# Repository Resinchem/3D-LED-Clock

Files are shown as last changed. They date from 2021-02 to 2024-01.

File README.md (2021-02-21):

# 3D-LED-Clock

## 3D Printed LED clock, countdown timer, temperature and scoreboard. Multiple control options. Now with OTA updates!
ClockMontage_HA_Small

## Local button control
ClockButtonControl_small

## Optional full settings and control via Home Assistant integration (MQTT)
clock_ha_scoreboard_small

## Full build details, wiring schematics and more at [ResinChem Tech Blog](https://resinchemtech.blogspot.com/2021/02/3d-printed-clock-scoreboard-and-more.html)

### For more information on installation, configuration and other details, see the [wiki](https://github.com/Resinchem/3D-LED-Clock/wiki).

Modified based on an original design by Leon van den Beukel.

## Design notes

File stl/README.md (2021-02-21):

# 3D Models

### All models can be printed without supports, **EXCEPT** the ControlEnclosure.stl, which should have supports enabled.

### To build the clock as designed, you will need to print each file by the listed quantity below:

| Qty | .stl File | Descrip | Color |
|:---:|---|---|---|
| 4 | Bottom.stl | Bottom Plates | Black |
| 4 | Top.stl | Top Plates | Black |
| 1 | Middle.stl | Middle top/bottom | Black |
| 1 | AttachBrackets_x6.stl | Rear attach brackets | Black |
| 1 | Backlid.stl | Back lid cover | Black |
| 1 | Stand_Spacers.stl | Clock Stand | Black |
| 1 | ButtonCase.stl | Push Button Enclosure | Black |
| 1 | ControlEnclosure.stl | Control board box | Black |
| 2 | Segment_hor_x6.stl | Six horiz. digit segments | White |
| 2 | Segment_vert_x8.stl | Eight vert. digit segments | White |
| 1 | Dot_x2.stl | Two dots | White |

Here are the settings I used for the Ender3 Pro:
- Layer Height: 0.2
- Infill: 20%
- Supports: No*
(\*Except for the Control Enclosure, which used supports touching buildplate)

#### See [ResinChem Tech Blog](https://resinchemtech.blogspot.com/2021/02/3d-printed-clock-scoreboard-and-more.html) for complete build details, parts list, wiring schematics and more.

All .stl files original design, except for ButtonCase.stl and ControlEnclosure, by Leon van den Beukel.

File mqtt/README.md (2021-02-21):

# MQTT Topic Commands and States

### MQTT use is optional, but if desired, a few steps must be taken

See the [MQTT page](https://github.com/Resinchem/3D-LED-Clock/wiki/MQTT-%5C---Home-Assistant-Integration) of the wiki for additional information.

The full list of topic states and commands, and valid payloads, can be found in the MQTT_Topics.pdf file.  Currently, there are over 30 states reported by the clock and over 20 commands that can be issued to the clock over MQTT.

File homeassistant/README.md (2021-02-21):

# Sample Home Assistant Files

### These are sample .yaml files that you can use or adapt to integrate the clock into Home Assistant

All communications between the clock (ESP8266) and Home Assistant are via MQTT.  Currently, the clock does not support MQTT discovery (anyone willing to take a stab at this is welcome to submit a PR), therefore all entites must be manually created in Home Assistant.  Obviously, you must have an MQTT broker running (either the integrated HA Mosquitto or a standalone broker).

MQTT is not required to build and use the clock. MQTT can be disabled within the Arudino sketch by setting MQTTMODE = 0 in the Settings.h file. See the [wiki](https://github.com/Resinchem/3D-LED-Clock/wiki) for additional details.

The samples include every possible sensor value and commands available for the clock.  You may not wish to include them all.

The entities also have long descriptive names in an attempt to clarify how they are used.

You can safely edit most of the yaml to fit your needs.  However, you cannot changes any of the MQTT topics or payloads without also modifying and uploading a new Arduino .ino file to the ESP8266 board.

For the Lovelace card, two custom cards (available via HACS) are necessary:

[Custom Button Card](https://github.com/custom-cards/button-card)

[Text-Divider-Row](https://github.com/iantrich/text-divider-row)

The files here are just starting examples.  Many, many more automations are possible and if you'd like to share any you develop, I'll post the interesting ones here.  But some examples might include:
- Change the clock color and/or brightness based on sun (or any other event)
- Sound the buzzer based on any other HA event or state change.
- Use the countdown feature to trigger other automations.

With over 30 MQTT sensors and over 20 MQTT commands, the possibilites are endless. See a full list of MQTT topcis in the MQTT folder.

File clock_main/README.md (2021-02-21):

# Arduino Files

There are some additional steps you must complete before uploading the .ino file to your board.  See the [Installation page](https://github.com/Resinchem/3D-LED-Clock/wiki/Installation) of the wiki for full installation instructions.

### Additional Information:
Full details on the build, including parts list, wiring schematics and more can be found at [ResinChem Tech Blog](https://resinchemtech.blogspot.com/2021/02/3d-printed-clock-scoreboard-and-more.html)

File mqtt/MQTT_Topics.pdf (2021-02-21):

## LED Clock MQTT Reporting States (clock publishes to these topics)

Topic Root | Topic | Subtopic1 | Subtopic2 | Payload | Values / Notes
stat/ledclock | /mode | | | mode (string) | Clock, Countdown, Temperature, Scoreboard
| /brightness | | | 0-255
| /clock | /display | | nn | 12 or 24
| | /color | /red | 0-255
| | /color | /green | 0-255
| | /color | /blue | 0-255
| /countdown | /starttime | | hh:mm:ss | Example: "00:15:00"
| | /status | | status as string | Running or Stopped
| | /color | /red | 0-255
| | /color | /green | 0-255
| | /color | /blue | 0-255
| | /colorfinalmin | /red | 0-255
| | /colorfinalmin | /green | 0-255
| | /colorfinalmin | /blue | 0-255
| | /colorpaused | /red | 0-255
| | /colorpaused | /green | 0-255
| | /colorpaused | /blue | 0-255
| /temperature | | | nn.n | Updates every 3 min or as specified in sketch
| | /symbol | | string char | C or F
| | /correction | | (-)n.n | Example: -6.5
| | /color | /red | 0-255
| | /color | /green | 0-255
| | /color | /blue | 0-255
| /scoreboard | /scoreleft | | 0-99
| | /scoreright | | 0-99
| | /colorleft | /red | 0-255
| | /colorleft | /green | 0-255
| | /colorleft | /blue | 0-255
| | /colorright | /red | 0-255
| | /colorright | /green | 0-255
| | /colorright | /blue | 0-255
Rebooting/restarting the clock will reset values to the defaults defined in the Settings.h file.

## All state topics begin with a topic of: stat/ledclock Examples: Get the current mode of the clock: MQTT Topic: stat/ledclock/mode Payload Returns: String of the clock mode (Clock, Countdown, Temperature or Scoreboard)

## Get the current RGB blue value setting of the scoreboard left score: MQTT Topic: stat/ledclock/scoreboard/colorleft/blue

Payload Returns: A value between 0-255 of the current RGB blue value for the left score.

## LED Clock Commands (clock subscribes to these topics)

Topic Root | Topic | Subtopic | Payload | Changes
Mode

Notes
cmnd/ledclock/ | /mode | n | Yes | Valid values: 0 (clock), 1 (countdown), 2
(temperature), 3 (scoreboard)
/brightness | nnn | Valid values: 0-255
/buzzer | nnnn | 1-9999 (milliseconds to sound)
/clock | /color | nnn,nnn,nnn | RGB: 0-255 range for each color
/display | nn | Yes | Valid values: 12 or 24
/settime | mmm dd yyyy;hh:mm:ss | Yes | mmm = Jan, Feb, Mar, etc.
/countdown | /color | nnn,nnn,nnn | RGB: 0-255 range for each color
/colorfinalmin | nnn,nnn,nnn | RGB: 0-255 range for each color
/colorpaused | nnn,nnn,nnn | RGB: 0-255 range for each color
/starttime | hh:mm:ss | Yes | Max of 23:59:59 (split and convert to
milliseconds)
/action | n | Yes | Valid values: 0 (Start), 1 (pause), 2 (stop &
reset), 3 (stop & clear)
/temperature | /color | nnn,nnn,nnn | RGB: 0-255 range for each color
/symbol | nn | Yes | Valid values: 12 (Celsius), 13 (Fahrenheit)
/correction | -n or +n | Yes | Examples: -4 or 2.5
/scoreboard | /colorleft | nnn,nnn,nnn | RGB: 0-255 range for each color
/colorright | nnn,nnn,nnn | RGB: 0-255 range for each color
/scoreleft | nn | Yes | Valid values: 0-99
/scoreright | nn | Yes | Valid values: 0-99
/scoreup | n | Yes | Increases by one. n=0 Left, n=1 Right, n=2 Both
/scoredown | n | Yes | Decreases by one. n=0 Left, n=1 Right, n=2 Both
/reset | n | Yes | Reset to zero: n=0 left, n=1 right, n=2 both

Changes Mode: Issuing the command also changes the current clock mode (e.g. changing the score also changes the clock mode to Scoreboard).

## Examples: Change the color of the clock to red: Topic: cmnd/ledclock/clock/color Payload: 255,0,0

## Set the starting time for the countdown to 2 minutes, 30 seconds: Topic: cmnd/ledclock/countdown/starttime Payload: 00:02:30

## Reset the scoreboard scores for both sides to zero: Topic: cmnd/ledclock/scoreboard/reset Payload: 2

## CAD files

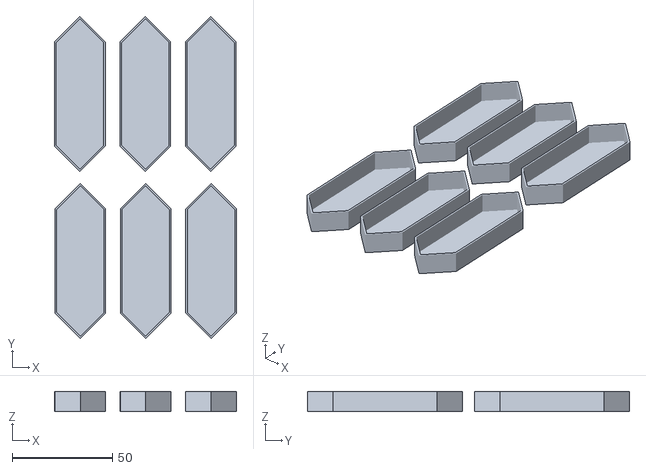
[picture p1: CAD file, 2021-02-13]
stl/Segment_hor_x6.stl
91.0 x 161.0 x 10.0

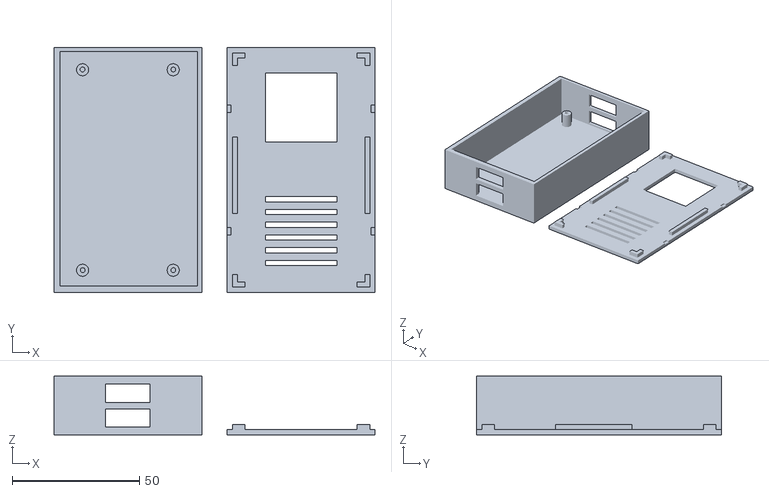
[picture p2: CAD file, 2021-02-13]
stl/ControlEnclosure.stl
126.0 x 96.0 x 23.0

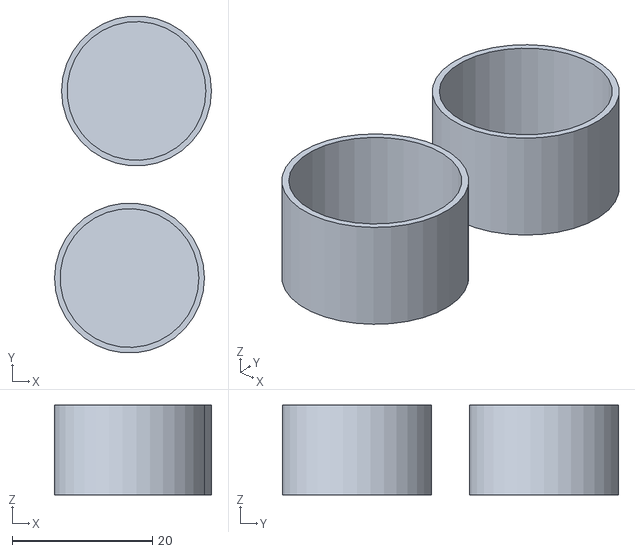
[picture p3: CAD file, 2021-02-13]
stl/Dot_x2.stl
22.4 x 48.0 x 12.8

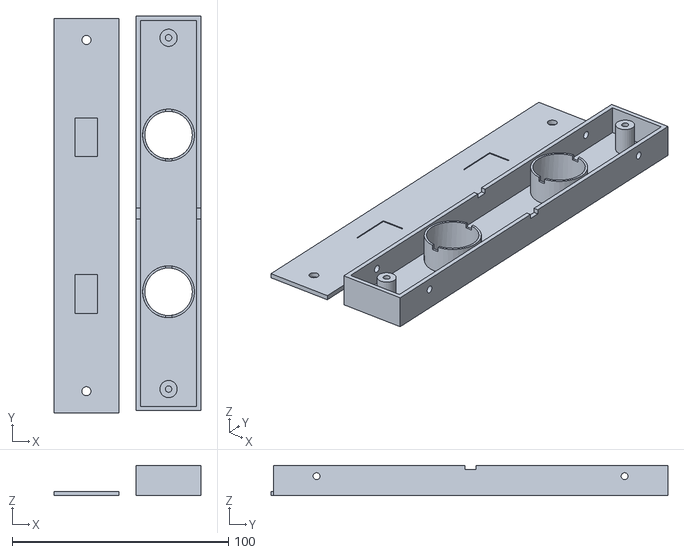
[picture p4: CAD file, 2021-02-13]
stl/Middle.stl
68.0 x 183.5 x 14.0

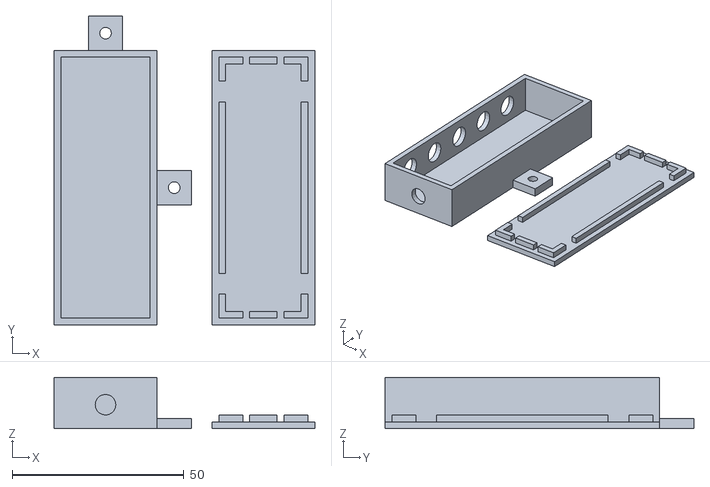
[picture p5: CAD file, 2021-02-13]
stl/ButtonCase.stl
76.0 x 90.0 x 15.0

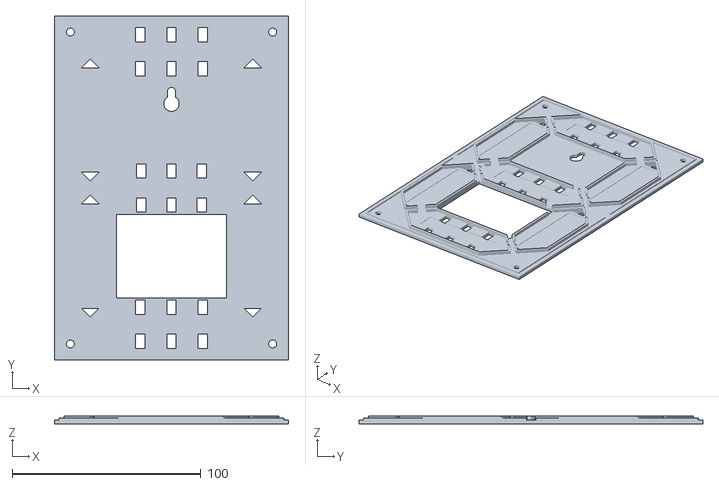
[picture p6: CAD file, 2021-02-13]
stl/Bottom.stl
124.2 x 182.5 x 4.00

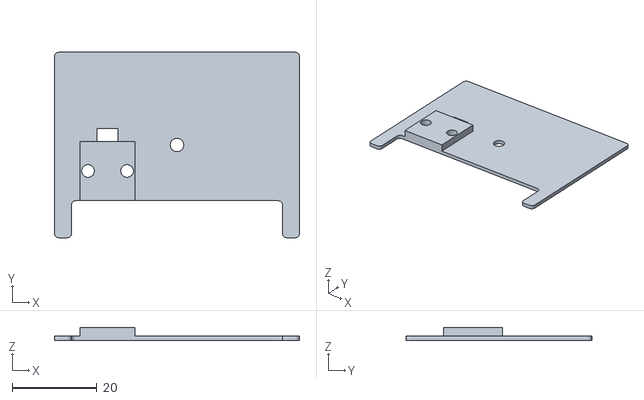
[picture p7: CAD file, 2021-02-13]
stl/Backlid.stl
57.7 x 43.7 x 3.00

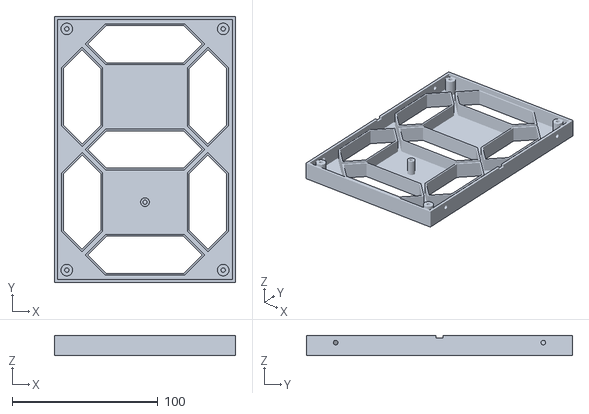
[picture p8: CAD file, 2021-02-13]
stl/Top.stl
124.2 x 182.5 x 14.0

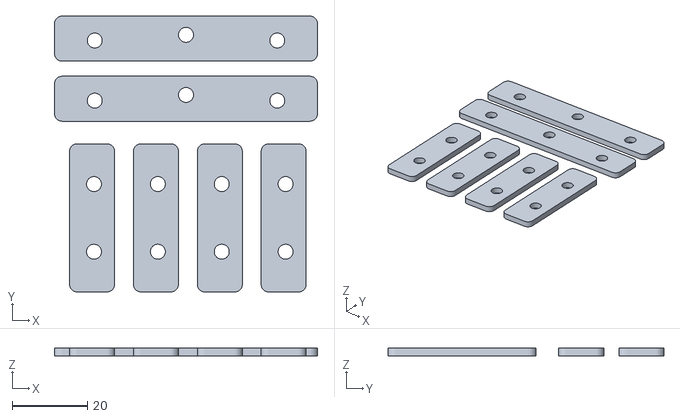
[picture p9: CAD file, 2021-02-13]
stl/AttachBrackets_x6.stl
70.0 x 73.4 x 2.00

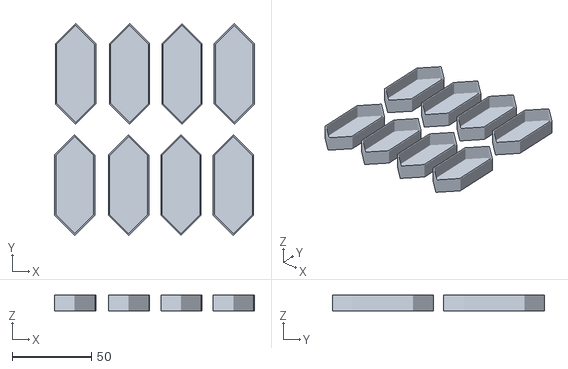
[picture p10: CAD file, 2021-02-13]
stl/Segment_vert_x8.stl
126.0 x 133.5 x 10.0

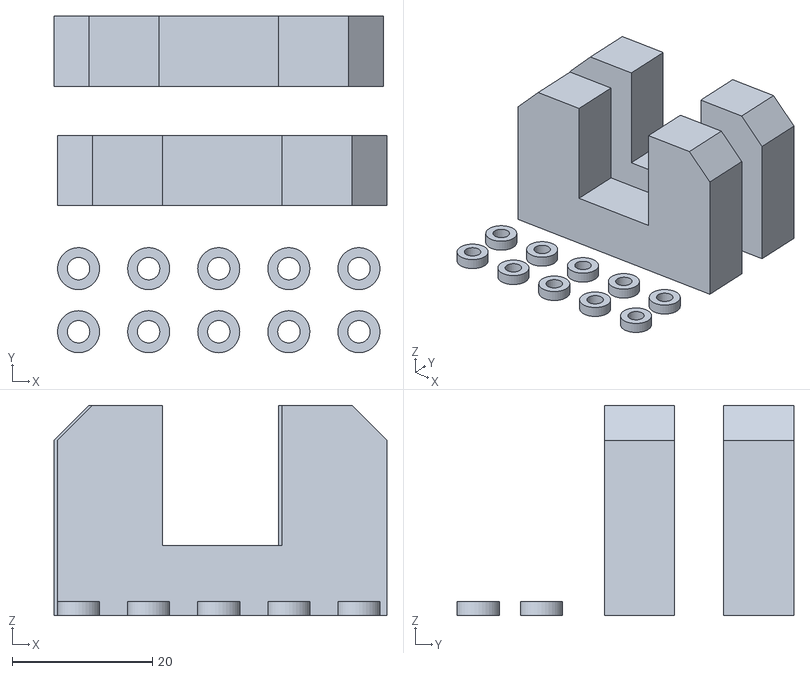
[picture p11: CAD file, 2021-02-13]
stl/Stand_Spacers.stl
47.5 x 48.0 x 30.0

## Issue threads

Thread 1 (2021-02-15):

Temperature not updating in Home Assistant when C/F or correction value entered

Resinchem, 2021-02-15:
When temperature display (C to F, or F to C) is changed via web app or Home Assistant, the displayed temperature in Home Assistant is not updated.  For example if 72.5 is displayed in Home Assistant and the mode is switched to C. the clock properly changes, but the value in the Home Assistant integration continues to display 72.5.

The same issue is seen when updating the temperature correction value.

Resinchem, 2021-02-15:
Fixed in release v0.93.

Requires new clock_main.ino.  Be sure to transfer your settings and options (MQTT IP, PORT, defaults, etc.) to the new clock_main.ino before flashing to your board.

Closed 2021-02-15.

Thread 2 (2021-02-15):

Clock changing mode when Home Assistant server restarts/reboots.

Resinchem, 2021-02-15:
When Home Assistant starts or reboots, the clock changes mode to Temperature, regardless of the mode it was set to prior to the HA reboot.

Resinchem, 2021-02-15:
Fixed in release v0.93. This was caused by the 'initial: ' value setting of the input_text entities for temperature correction.  You can either download the updated input_text.yaml and integrate into your current one, or simply remove the 'initial:' property for the following input_text entities:

input_text.led_clock_temperature_correction
input_text.led_clock_countdown_starttime

Closed 2021-02-15.

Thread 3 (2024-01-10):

Compilation error after disable MQTT in settings.h

JureqB, 2024-01-10:
...  Documents\Arduino\3D-LED-Clock-1.00\clock_main\clock_main.ino: In function 'boolean reconnect()':
clock_main:95:37: error: 'mqttUser' was not declared in this scope
   95 |   if (client.connect("ClockClient", mqttUser, mqttPW)) {
      |                                     ^~~~~~~~
clock_main:95:47: error: 'mqttPW' was not declared in this scope
   95 |   if (client.connect("ClockClient", mqttUser, mqttPW)) {
      |                                               ^~~~~~
exit status 1
'mqttUser' was not declared in this scope

Resinchem, 2024-01-10:
There were some missing checks for the MQTT enabled status.  These have been fixed with release v1.01.

Closed 2024-01-10.

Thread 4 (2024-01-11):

#define MQTTMODE 0 in settings.h still generating error

JureqB, 2024-01-11:
...  Documents\Arduino\3D-LED-Clock-1.01\clock_main\clock_main.ino: In function 'boolean reconnect()':
clock_main:106:1: error: no return statement in function returning non-void [-Werror=return-type]
  106 | }

Resinchem, 2024-01-11:
I'm not able to duplicate this issue as the code compiles fine for me whether the MQTT mode in settings is set to either 1 or 0.  However, you can try adding an #else statement in the reconnect function to see if it solves your issue:

```
boolean reconnect() {
#if (WIFIMODE == 1 || WIFIMODE == 2) && (MQTTMODE == 1)
  if (client.connect("ClockClient", mqttUser, mqttPW)) {
    // Once connected, publish an announcement...
    client.publish("stat/ledclock/status", "connected");
    // ... and resubscribe
    client.subscribe("cmnd/ledclock/#");
  }
  return client.connected();
#else
  return true;
#endif
}
```
You can try adding the #else and return true lines to your version and see if it resolves the issue.  But it shouldn't be required as I am not getting any compilation errors without it.  As an FYI, I am using the Arduino IDE v1.8.16.

JureqB, 2024-01-11:
I am using 1.18.19 (Windows Store 1.8.57.0)

When I have MQTT enabled, I can compile oryginal a sketch and only this message appears:

In file included from C:\Users\xyz\Documents\Arduino\libraries\FastLED\src/FastLED.h:79,
                 from C:\Users\xyz\Documents\Arduino\3D-LED-Clock-main\clock_main\clock_main.ino:13:
C:\Users\xyz\Documents\Arduino\libraries\FastLED\src/fastspi.h:157:23: note: '#pragma message: No hardware SPI pins defined.  All SPI access will default to bitbanged output'
  157 | #      pragma message "No hardware SPI pins defined.  All SPI access will default to bitbanged output"
      |                       ^~~~~~~~~~~~~~~~~~~~~~~~~~~~~~~~~~~~~~~~~~~~~~~~~~~~~~~~~~~~~~~~~~~~~~~~~~~~~~~~

JureqB, 2024-01-11:
Serial monitor at 74880 baud received this:

15:55:26.108 ->  ets Jan  8 2013,rst cause:2, boot mode:(3,6)
15:55:26.108 ->
15:55:26.108 -> load 0x4010f000, len 3424, room 16
15:55:26.155 -> tail 0
15:55:26.155 -> chksum 0x2e
15:55:26.155 -> load 0x3fff20b8, len 40, room 8
15:55:26.155 -> tail 0
15:55:26.155 -> chksum 0x2b
15:55:26.155 -> csum 0x2b
15:55:26.155 -> v000618e0
15:55:26.155 -> ~ld
15:55:26.202 -> rf cal sector: 1020
15:55:26.202 -> freq trace enable 0
15:55:26.202 -> rf[112] : 0⸮

Resinchem, 2024-01-11:
From the serial monitor, the rst cause:2, boot mode(3,6) is usually due to a watchdog reset.  This means something is hanging in your program.  It could be the real time clock, connection to wifi taking longer than expected, or some other peripheral that isn't wired correctly and is not reporting back as expected.  I'd recommend verifying all your wiring, and if necessary, add some Serial.println() statements to various sections of the setup code to see where the application is hanging up.

Also the fact that you are seeing the clock AP being broadcast means that it isn't connecting to your wifi.  Verify your WiFi settings in Credentials.h.  You can also try setting WIFIMODE to 1 in the Settings.h, meaning that it will only connect to your wifi and not broadcast a local AP hotspot.

Unfortunately, I cannot duplicate the issue.  Mine compiles and runs just fine, with or without MQTT.  The 3D printed clock has been in operation for nearly 3 years now and I haven't seen or noticed any watchdog resets like you are reporting, so I don't believe this is a firmware issue but something likely due to your particular build.

Resinchem, 2024-01-11:
OK... our messages crossed paths.  First, the SPI message you are seeing is normal and isn't an error.  Next, the watchdog resets are likely a result of the missing RTC clock module.  The clock calls this module to get the current time... and I'm guessing that since you don't have the clock module connected, this is what is causing the reboots.

If the clock is constantly rebooting due to this watchdog error, it probably also explains why you cannot bring up the web page... the ESP is constantly rebooting and is unable to start the web server and respond to the web request.

For this particular code and the way it is written, the RTC module is required.

JureqB, 2024-01-11:
I don't currently have the RTC module, once I put it all together I will let you know if there is any improvement, thank you for your help :)

Resinchem, 2024-01-11:
No problem.  Glad to help.  This is one of my earliest Arduino projects and there is a ton of room for improvement.  It's one of many projects I'd like to revisit and clean up the code... if I can ever find time to do it.

I'm going to go ahead and close this issue for now.  If you have problems or errors after connecting the RTC module, feel free to open a new issue.

Resinchem, 2024-02-02:
First off, you should not be trying to power everything via USB.  The LEDs can pull over 4A depending upon color/brightness.  It is recommended that no more than about 500 mA be pulled on he 5V pin on the D1 Mini/ESP8266.  Trying to run everything via USB will likely damage or destroy the ESP board at some point.  I think my build recommended a 5V 8A power supply and the board, as built, supplies power to the LEDs and controller in parallel so that the total current isn't running through the ESP board.

That being said, the error you are getting is a watchdog reset.  This is generally due to something hanging or taking too long to complete, which results in a reboot of the board.  The fact that the 'points' are delayed at times and that they work fine when in other modes (such as timer), points to something hanging up or delaying in the updateClock process.  And the one thing that is different about that process is the real time clock module (RTC).  It is highly likely that it is this module that is causing a delay when it is called (Rtc.GetDateTime).  This would explain both the delay in the dots updating and the reboot if the delay is too long.

So you probably need to focus on the RTC module... assure it is properly wired, has a fresh battery, etc.  It could also be causing issues if underpowered (e.g when powering via USB or an underpowered power supply). You should also verify that it is one of the supported chip sets for the RTC library being used.  You can get that info here:  [RTC Library Wiki](https://github.com/Makuna/Rtc/wiki).

But the fact that other modes work fine and only the clock is having these issues points to either a problem with the RTC module and/or the system being underpowered.  I'd recommend using a power supply that can supply at least 5A, preferably 8-10A.

JureqB, 2024-02-06:
I have used various 3-10A power supplies and it does not matter. Current consumption during operation does not exceed 1.5A. Only when I turned off Wi-Fi+AP mode and left Wi-Fi anly (#define WIFIMODE 1) did the dots blink as they should. So it's a program problem, not an external one.

Resinchem, 2024-02-06:
Do you have MQTT configured and enabled (MQTTMODE = 1)?  There are really only two things in the main loop that could cause a significant delay (which would impact the blinking dots) or even a watchdog reset... waiting on the RTC module to return a valid value, or trying to connect/reconnect to the MQTT broker.  The Wifi or Wifi+AP mode really shouldn't make a difference.  The only difference between these two settings is whether the ESP continues to broadcast its hotspot after connecting to wifi (mode 2) or turns it off (mode 1).

It is entirely possible that I missed something, especially if MQTT is not configured or off... or I missed a combination check of both Wifi and MQTT modes to determine whether to use MQTT or not.  But I have successfully been running this code for multiple years on this 3D clock.  I also have 3 matrix clocks, and while the output to LEDs are different, the rest of the application logic is basically the same.  But I do have MQTT enabled for all of these.
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
JureqB, 2024-02-06:
I don't have MQTT (MQTTMODE 0   MQTTSERVER "0.0.0.0"  MQTTPORT 1883) , but my first problem, as you remember, was that I couldn't compile the program after turning off MQTT in settings.h

Resinchem, 2024-02-06:
OK... thanks.  Even though I fixed the compile errors, I most likely I missed something somewhere where it is still trying to connect to your non-existent MQTT broker.  Since I'm using MQTT, I didn't actually install and test the last fix... just the fact that it compiled.

Give me a little time and as soon as I get a chance, I'll circle back to the code and go over it again and assure that it is not making any calls to MQTT if the option is disabled.

Resinchem, 2024-02-06:
OK... I've reviewed the code and I don't see anything related to MQTT.  If you set MQTTMODE = 0, most of MQTT functions and processes don't even get compiled into the firmware.  But I was looking back through what we discussed above and something caught my eye.  You said that the dots function normally for things like the timer, but are only acting unusual and delaying when in clock mode.  In the main loop, every 1 second it calls the method to update the display (either via updateClock, updateCountdown, updateScoreboard, etc.).

Well, in the updateClock function is this call that isn't present in any of the other update methods:

```  RtcDateTime now = Rtc.GetDateTime();```

So this points back to a potential issue with the clock module and/or its communication with the D1 Mini.  The clock would appear to keep the correct time, as it only updates once per minute... and that timer is kept within the main loop.  But the dot update (toggling the dots on/off) is occurring within the individual updates (clock, timer, etc.).  So, if the clock update is taking too long to communicate with the RTC module, the dots will be delayed in turning off/on, but the master loop keeps counting, so the minute will roll forward at the 60 second mark (unless it is delayed in the loop right at that moment).  That would also explain why the dots work normally in the timer mode, as it isn't calling the RTC module.  Here's a test you can try that might confirm the problem:

Start a stopwatch right when a new minute is displayed.  Watch it for 5 or 10 minutes.  The clock should update to the next minute right at 60 seconds.  If you are seeing a one or two second difference (or even greater), then the updateClock procedure is causing a delay.  But since the 60 second counter continues to run in the main loop, you may not see this right away.  So if you don't see a difference in the first 5-10 minutes, let both the stopwatch and clock run and come back every so often (maybe every hour or two) and see if the clock is still in sync with the stopwatch... updating the time at the top of minute on the stopwatch.  If the update has drifted over time, this also indicates that the clockUpdate is taking too long and causing a drift over time.  Unless you are pressing a bunch of the pushbuttons (these actually consume a couple hundred milliseconds), then the clock time should not drift by more than a couple of seconds MAX over a 24-hour period.

I don't think MQTT is the issue any longer.  But it does appear to be something limited to the clock mode and the only real difference between that mode and the other modes is the call made to the RTC library/module.  Please let me know what you find based on the above and we can take it from there.

Closed 2024-01-11.

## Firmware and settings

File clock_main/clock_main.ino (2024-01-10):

/*
 * VERSION 1.01
 * January 10, 2024
 * See Release notes for details on changes
 * By ResinChem Tech - licensed under Creative Commons Attribution-NonCommercial-ShareAlike 4.0 International License
 * Adapted from original work published by Leon van den Beukel 
*/
#include <Wire.h>
#include <RtcDS3231.h>                        // Include RTC library by Makuna: https://github.com/Makuna/Rtc
#include <ESP8266WiFi.h>
#include <ESP8266WebServer.h>
#include <ESP8266HTTPUpdateServer.h>
#include <FastLED.h>
#include <FS.h>                               // Please read the instructions on http://arduino.esp8266.com/Arduino/versions/2.3.0/doc/filesystem.html#uploading-files-to-file-system
#include <PubSubClient.h>
#include <ESP8266mDNS.h>                      // NEW for v1.00
#include <WiFiUdp.h>                          // NEW for v1.00
#include <ArduinoOTA.h>                       // NEW for v1.00
#include "Settings.h"
#define countof(a) (sizeof(a) / sizeof(a[0]))

// ==============================================================================================
//  *** REVIEW THE Settings.h and Credentials.h FILES AND SET TO MATCH YOUR ENVIRONMENT/BUILD ***
//      You may also set various default boot options in the Settings.h file
// ==============================================================================================
// Do not change any values below unless you are sure you know what you are doing!

byte oldMode = 0;
int oldTemp = 0;
bool ota_flag = true;               //v1.00
uint16_t ota_time_elapsed = 0;      //v1.00
uint16_t ota_time_window = 2500;    //v1.00 minimum time on boot for IP address to show in IDE ports


#if defined(WIFIMODE) && (WIFIMODE == 0 || WIFIMODE == 2)
  const char* APssid = "CLOCK_AP";        
  const char* APpassword = "1234567890";  
#endif
  
#if defined(WIFIMODE) && (WIFIMODE == 1 || WIFIMODE == 2)
  #include "Credentials.h"                    // Edit this file in the same directory as the .ino file and add your own credentials
  const char *ssid = SID;
  const char *password = PW;
  #if (WIFIMODE == 1 || WIFIMODE == 2) && (MQTTMODE == 1)    // MQTT only available when on local wifi
    const char *mqttUser = MQTTUSERNAME;
    const char *mqttPW = MQTTPWD;
  #endif
#endif
WiFiClient espClient;
#if (WIFIMODE == 1 || WIFIMODE == 2) && (MQTTMODE == 1)
  PubSubClient client(espClient);   
#endif
long lastReconnectAttempt = 0;

RtcDS3231<TwoWire> Rtc(Wire);
ESP8266WebServer server(80);
ESP8266HTTPUpdateServer httpUpdateServer;
CRGB LEDs[NUM_LEDS];

unsigned long prevTime = 0;
unsigned long prevTempTime = 0;                   // To limit MQTT Temp updates so as not to flood broker
byte r_val = 255;
byte g_val = 0;
byte b_val = 0;
bool dotsOn = true;
unsigned long countdownMilliSeconds;
unsigned long endCountDownMillis;

//
bool mqttConnected = false;                       // Will be set to true upon valid connection
bool timerRunning = false; 
unsigned long remCountdownMillis = 0;             // Stores value on pause/resume
unsigned long initCountdownMillis = 0;            // Stores initial last countdown value for reset    
//
long numbers[] = {
  0b000111111111111111111,  // [0] 0
  0b000111000000000000111,  // [1] 1
  0b111111111000111111000,  // [2] 2
  0b111111111000000111111,  // [3] 3
  0b111111000111000000111,  // [4] 4
  0b111000111111000111111,  // [5] 5
  0b111000111111111111111,  // [6] 6
  0b000111111000000000111,  // [7] 7
  0b111111111111111111111,  // [8] 8
  0b111111111111000111111,  // [9] 9
  0b000000000000000000000,  // [10] off
  0b111111111111000000000,  // [11] degrees symbol
  0b000000111111111111000,  // [12] C(elsius)
  0b111000111111111000000,  // [13] F(ahrenheit)
  0b000111000111111111111,  // [14] U
  0b111111111111111000000,  // [15] P
  0b000000000111111111000,  // [16] L
  0b111111000000111111111,  // {17] d
};

boolean reconnect() {
#if (WIFIMODE == 1 || WIFIMODE == 2) && (MQTTMODE == 1)
  if (client.connect("ClockClient", mqttUser, mqttPW)) {
    // Once connected, publish an announcement...
    client.publish("stat/ledclock/status", "connected");
    // ... and resubscribe
    client.subscribe("cmnd/ledclock/#");
  }
  return client.connected();
#endif
}

void setup() {
  pinMode(3, FUNCTION_3);
  pinMode(1, FUNCTION_3);
  pinMode(COUNTDOWN_OUTPUT, OUTPUT);
  pinMode(MODE_PIN, INPUT_PULLUP);
  pinMode(V1_PIN, INPUT_PULLUP);
  pinMode(V0_PIN, INPUT_PULLUP);
  pinMode(H1_PIN, INPUT_PULLUP);
  pinMode(H0_PIN, INPUT_PULLUP);
  delay(200);

  // RTC DS3231 Setup
  Rtc.Begin();    
  RtcDateTime compiled = RtcDateTime(__DATE__, __TIME__);

  if (!Rtc.IsDateTimeValid()) {
      if (Rtc.LastError() != 0) {
          // we have a communications error see https://www.arduino.cc/en/Reference/WireEndTransmission for what the number means
          // Serial.print("RTC communications error = ");
          // Serial.println(Rtc.LastError());
      } else {
          // Common Causes:
          //    1) first time you ran and the device wasn't running yet
          //    2) the battery on the device is low or even missing
          // Serial.println("RTC lost confidence in the DateTime!");
          // following line sets the RTC to the date & time this sketch was compiled
          // it will also reset the valid flag internally unless the Rtc device is
          // having an issue
          Rtc.SetDateTime(compiled);
      }
  }

  WiFi.setSleepMode(WIFI_NONE_SLEEP);  

  delay(200);

  FastLED.addLeds<WS2812B, DATA_PIN, GRB>(LEDs, NUM_LEDS);  
  FastLED.setDither(false);
  FastLED.setCorrection(TypicalLEDStrip);
  FastLED.setMaxPowerInVoltsAndMilliamps(5, MILLI_AMPS);
  fill_solid(LEDs, NUM_LEDS, CRGB::Black);
  FastLED.show();

  // WiFi - AP Mode or both
#if defined(WIFIMODE) && (WIFIMODE == 0 || WIFIMODE == 2) 
  WiFi.mode(WIFI_AP_STA);
  WiFi.softAP(APssid, APpassword);    // IP is usually 192.168.4.1
#endif

  // WiFi - Local network Mode or both
#if defined(WIFIMODE) && (WIFIMODE == 1 || WIFIMODE == 2) 
  byte count = 0;
  WiFi.begin(ssid, password);
  while (WiFi.status() != WL_CONNECTED) {
    // Stop if cannot connect
    if (count >= 60) {
      // Could not connect to local WiFi      
      return;
    }
    delay(500);
    LEDs[count] = CRGB::Green;
    FastLED.show();
    count++;
  }
  IPAddress ip = WiFi.localIP();
#endif   
  // MQTT - Only if on local wifi and MQTT enabled
#if defined(MQTTMODE) && (MQTTMODE == 1 && (WIFIMODE == 1 || WIFIMODE == 2))
  byte mcount = 0;
  client.setServer(MQTTSERVER, MQTTPORT);
  client.setCallback(callback);
  while (!client.connected( )) {
    client.connect("ClockClient", mqttUser, mqttPW);
    if (mcount >= 60) {
      // Could not connect to MQTT broker
      return;
    }
    delay(500);
    LEDs[mcount] = CRGB::Blue;
    FastLED.show();
    mcount++;
  }
  mqttConnected = true;
  client.subscribe("cmnd/ledclock/#");
  client.publish("stat/ledclock/status", "connected");
  oldMode = clockMode;
  updateMqttMode();
#endif
  httpUpdateServer.setup(&server);
  
  //OTA Updates - new in V1.00
  ArduinoOTA.setHostname("led-clock");
  ArduinoOTA.onStart([]() {
    String type;
    if (ArduinoOTA.getCommand() == U_FLASH) {
      type = "sketch";
    } else { // U_FS
      type = "filesystem";
    }
    // NOTE: if updating FS this would be the place to unmount FS using FS.end()
  });
  ArduinoOTA.begin();
  
  // ************ Update MQTT stat vals with boot values *****************
  if (mqttConnected) {
    updateMqttBrightness(brightness);
    updateMqttClockDisplay(hourFormat);
    updateMqttTemperature();
    updateMqttTempSymbol(temperatureSymbol);
    updateMqttTempCorrection();
    updateMqttCountdownStartTime(initCountdownMillis);
    updateMqttCountdownStatus(timerRunning);
    updateMqttScoreboardScores();
    // Default boot colors
    updateMqttColor(0, clockColor.r, clockColor.g, clockColor.b);  
    updateMqttColor(1, countdownColor.r, countdownColor.g, countdownColor.b);
    updateMqttColor(2, countdownColorPaused.r, countdownColorPaused.g, countdownColorPaused.b);
    updateMqttColor(3, countdownColorFinalMin.r, countdownColorFinalMin.g, countdownColorFinalMin.b);
    updateMqttColor(4, temperatureColor.r, temperatureColor.g, temperatureColor.b);
    updateMqttColor(5, scoreboardColorLeft.r, scoreboardColorLeft.g, scoreboardColorLeft.b);
    updateMqttColor(6, scoreboardColorRight.r, scoreboardColorRight.g, scoreboardColorRight.b);
  }
  // Handlers
  server.on("/color", HTTP_POST, []() {    
    r_val = server.arg("r").toInt();
    g_val = server.arg("g").toInt();
    b_val = server.arg("b").toInt();
    clockColor = CRGB(r_val, g_val, b_val);
    server.send(200, "text/json", "{\"result\":\"ok\"}");
    if (mqttConnected) {
      updateMqttColor(0, r_val, g_val, b_val);
    }
  });

  server.on("/setdate", HTTP_POST, []() { 
    // Sample input: date = "Dec 06 2009", time = "12:34:56"
    // Jan Feb Mar Apr May Jun Jul Aug Sep Oct Nov Dec
    String datearg = server.arg("date");
    String timearg = server.arg("time");
    char d[12];
    char t[9];
    datearg.toCharArray(d, 12);
    timearg.toCharArray(t, 9);
    RtcDateTime compiled = RtcDateTime(d, t);
    Rtc.SetDateTime(compiled);   
    clockMode = 0;     
    server.send(200, "text/json", "{\"result\":\"ok\"}");
  });

  server.on("/brightness", HTTP_POST, []() {    
    brightness = server.arg("brightness").toInt();    
    server.send(200, "text/json", "{\"result\":\"ok\"}");
    if (mqttConnected) {
      //char outpayload[3];
      //sprintf(outpayload, "%3u", server.arg("brightness").toInt());
      //client.publish("stat/ledclock/brightness", outpayload, true);
      updateMqttBrightness(brightness);
    }
  });
  
  server.on("/countdown", HTTP_POST, []() {    
    countdownMilliSeconds = server.arg("ms").toInt();     
    byte cd_r_val = server.arg("r").toInt();
    byte cd_g_val = server.arg("g").toInt();
    byte cd_b_val = server.arg("b").toInt();
    digitalWrite(COUNTDOWN_OUTPUT, LOW);
    countdownColor = CRGB(cd_r_val, cd_g_val, cd_b_val); 
    endCountDownMillis = millis() + countdownMilliSeconds;
    initCountdownMillis = countdownMilliSeconds;          // store for reset to init value
    allBlank(); 
    clockMode = 1;    
    timerRunning = true; 
    server.send(200, "text/json", "{\"result\":\"ok\"}");
    if (mqttConnected) {
      updateMqttColor(1, server.arg("r").toInt(), server.arg("g").toInt(), server.arg("b").toInt());
      updateMqttCountdownStartTime(initCountdownMillis);
      updateMqttCountdownStatus(timerRunning);
    }
  });

  server.on("/temperature", HTTP_POST, []() {   
    temperatureCorrection = server.arg("correction").toInt();
    temperatureSymbol = server.arg("symbol").toInt();
    clockMode = 2;     
    server.send(200, "text/json", "{\"result\":\"ok\"}");
    if (mqttConnected) {
      //char outCorr[10];
      //sprintf(outCorr, "%4.1f", temperatureCorrection);
      //client.publish("stat/ledclock/temperature/correction", outCorr, true);
      updateMqttTempCorrection();
      updateMqttTempSymbol(temperatureSymbol);
      updateMqttTemperature();
    }
  });  

  server.on("/scoreboard", HTTP_POST, []() {   
    scoreboardLeft = server.arg("left").toInt();
    scoreboardRight = server.arg("right").toInt();
    scoreboardColorLeft = CRGB(server.arg("rl").toInt(),server.arg("gl").toInt(),server.arg("bl").toInt());
    scoreboardColorRight = CRGB(server.arg("rr").toInt(),server.arg("gr").toInt(),server.arg("br").toInt());
    clockMode = 3;     
    server.send(200, "text/json", "{\"result\":\"ok\"}");
    if (mqttConnected) {
      updateMqttColor(5, server.arg("rl").toInt(),server.arg("gl").toInt(),server.arg("bl").toInt());
      updateMqttColor(6, server.arg("rr").toInt(),server.arg("gr").toInt(),server.arg("br").toInt());
      updateMqttScoreboardScores();
    }
  });  

  server.on("/hourformat", HTTP_POST, []() {   
    hourFormat = server.arg("hourformat").toInt();
    clockMode = 0;     
    server.send(200, "text/json", "{\"result\":\"ok\"}");
    if (mqttConnected) {
      //char outpayload[2];
      //sprintf(outpayload, "%2u", server.arg("hourformat").toInt());
      //client.publish("stat/ledclock/clock/display", outpayload, true);
      updateMqttClockDisplay(hourFormat);
    }
  }); 

  server.on("/clock", HTTP_POST, []() {       
    clockMode = 0;     
    server.send(200, "text/json", "{\"result\":\"ok\"}");
  });  

  // New web commands for OTA updates - v1.00
  server.on("/restart",[](){
    server.send(200, "text/html", "<h1>Restarting...</h1>");
    delay(1000);
    ESP.restart();
  });
  server.on("/otaupdate",[]() {
    server.send(200, "text/html", "<h1>Ready for upload...<h1><h3>Start upload from IDE now</h3>");
    ota_flag = true;
    ota_time_window = 20000;
    ota_time_elapsed = 0;
  });
  
  // Before uploading the files with the "ESP8266 Sketch Data Upload" tool, zip the files (if not already zipped) with the command "gzip -r ./data/" (on Windows you can do this with a Git Bash)
  // *.gz files are automatically unpacked and served from your ESP (so you don't need to create a handler for each file).
  server.serveStatic("/", SPIFFS, "/", "max-age=86400");
  server.begin();     

  SPIFFS.begin();
  Dir dir = SPIFFS.openDir("/");
  while (dir.next()) {
    String fileName = dir.fileName();
    size_t fileSize = dir.fileSize();
  }
  
  digitalWrite(COUNTDOWN_OUTPUT, LOW);

};

// *************** MQTT Message Processing *********************
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
void loop(){
  // v1.00: OTA Update - on boot will pause for 2.5 seconds (needed to broadcast network mDNS)
  // When OTA flag set via HTML call, time to upload set at 20 sec. via server callback above.  Alter there if more time desired.
  if (ota_flag) {
    displayOTA();
    uint16_t ota_time_start = millis();
    while (ota_time_elapsed < ota_time_window) {
      ArduinoOTA.handle();  
      ota_time_elapsed = millis()-ota_time_start;   
      delay(10); 
    }
    ota_flag = false;
  }

  server.handleClient();
#if (WIFIMODE == 1 || WIFIMODE == 2) && (MQTTMODE == 1)
  if (MQTTMODE == 1) {
    if (!client.connected()) {
      long now = millis();
      if (now - lastReconnectAttempt > 60000) {   //attempt reconnect once per minute. Drop usually a result of Home Assistant/broker server restart
        lastReconnectAttempt = now;
        // Attempt to reconnect
        if (reconnect()) {
          lastReconnectAttempt = 0;
        }
      }
    } else {
      // Client connected
      client.loop();
    }
  }
#endif
  int modeReading = digitalRead(MODE_PIN);
  int v1Reading = digitalRead(V1_PIN);
  int v0Reading = digitalRead(V0_PIN);
  int h1_Reading = digitalRead(H1_PIN);
  int h0_Reading = digitalRead(H0_PIN);

  // Mode button (White button)
  if (modeReading == LOW) { 
    clockMode = clockMode + 1; 
    delay(500);
  }
  if (clockMode > 3) {         
    clockMode = 0;
  }

  // V+ button: Increase visitor score / Add 1 min to timer when stopped (Red button)
  if (v1Reading == LOW && h0_Reading == !LOW) {           // Assure blue button not also pressed (resetting)
    if (clockMode == 3) {
      scoreboardLeft = scoreboardLeft + 1;
      if (scoreboardLeft > 99)
        scoreboardLeft = 0;
      if (mqttConnected)
        updateMqttScoreboardScores();
      } else if (clockMode == 1 && !timerRunning) {
      initCountdownMillis = initCountdownMillis + 60000;
      countdownMilliSeconds = initCountdownMillis;
      remCountdownMillis = initCountdownMillis;
      endCountDownMillis = countdownMilliSeconds + millis();
      if (mqttConnected)
        updateMqttCountdownStartTime(initCountdownMillis);
    }
    delay(500);
  }

  // V- button: Decrease visitor score / Add 5 seconds to timer when stopped (Green button)
  if (v0Reading == LOW) {
    if (clockMode == 3) {
      if (scoreboardLeft > 0) 
        scoreboardLeft = scoreboardLeft - 1;
      if (mqttConnected)
        updateMqttScoreboardScores();

    } else if (clockMode == 1 && !timerRunning) {
      initCountdownMillis = initCountdownMillis + 5000;
      countdownMilliSeconds = initCountdownMillis;
      remCountdownMillis = initCountdownMillis;
      endCountDownMillis = countdownMilliSeconds + millis();
      if (mqttConnected)
        updateMqttCountdownStartTime(initCountdownMillis);
    }
    delay(500);
  }

  // H+ button: Increase home score / start countdown (Yellow button)
  if (h1_Reading == LOW) {
    if (clockMode == 3) {
      scoreboardRight = scoreboardRight + 1;
      if (scoreboardRight > 99) 
        scoreboardRight = 0;
      if (mqttConnected)
        updateMqttScoreboardScores();

    } else if (clockMode == 1) {
      if (!timerRunning && remCountdownMillis > 0) {
      endCountDownMillis = millis() + remCountdownMillis;
      timerRunning = true;
      if (mqttConnected)
        updateMqttCountdownStatus(timerRunning);
      }
    }
    delay(500);
  }

  // H- button: Decrease home score / stop countdown (Blue button)
  if (h0_Reading == LOW && v1Reading == !LOW) {           // Assure Red button also not pressed (resetting)
    if (clockMode == 3) {
      if (scoreboardRight > 0) 
        scoreboardRight = scoreboardRight - 1;
      if (mqttConnected)
        updateMqttScoreboardScores();

    } else if (clockMode == 1) {
      if (!timerRunning) {
        // Reset timer to last start value
        countdownMilliSeconds = initCountdownMillis;
        remCountdownMillis = initCountdownMillis;
        endCountDownMillis = countdownMilliSeconds + millis();
      } else {
        timerRunning = false;
        if (mqttConnected)
          updateMqttCountdownStatus(timerRunning);
      }
    }
    delay(500);
  }

  // Both V+ and H- buttons (red and blue) pressed - Reset scores / set coundown timer to 0:00
  if (v1Reading == LOW && h0_Reading == LOW) {
    if (clockMode == 3) {
      scoreboardLeft = 0;
      scoreboardRight = 0;
      if (mqttConnected)
        updateMqttScoreboardScores();
    } else if (clockMode == 1  && !timerRunning) {
      countdownMilliSeconds = 0;
      endCountDownMillis = 0;
      remCountdownMillis = 0;
      initCountdownMillis = 0;
      if (mqttConnected)
        updateMqttCountdownStartTime(initCountdownMillis);
    }
    delay(500);
  }
  
  unsigned long currentMillis = millis();  
  if (currentMillis - prevTime >= 1000) {
    prevTime = currentMillis;

    if (clockMode == 0) {
      updateClock();
    } else if (clockMode == 1) {
      updateCountdown();
    } else if (clockMode == 2) {
      updateTemperature();      
    } else if (clockMode == 3) {
      updateScoreboard();            
    } 


    FastLED.setBrightness(brightness);
    FastLED.show();
    // Update MQTT here if enabled and connected
    if (mqttConnected) {
      unsigned long currTempMillis = millis();
      // Mode
      if (clockMode != oldMode) {
        updateMqttMode();
        oldMode = clockMode;
      }
      if ((temperatureUpdatePeriod > 0) && (currTempMillis - prevTempTime >= temperatureUpdatePeriod)) { 
        prevTempTime = currTempMillis;     
        updateMqttTemperature();
      }
    }
  }   
}

void displayNumber(byte number, byte segment, CRGB color) {
  /*
   * 
      __ __ __        __ __ __          __ __ __        12 13 14  
    __        __    __        __      __        __    11        15
    __        __    __        __      __        __    10        16
    __        __    __        __  42  __        __    _9        17
      __ __ __        __ __ __          __ __ __        20 19 18  
    __        65    __        44  43  __        21    _8        _0
    __        __    __        __      __        __    _7        _1
    __        __    __        __      __        __    _6        _2
      __ __ __       __ __ __           __ __ __       _5 _4 _3   
   */
 
  // segment from left to right: 3, 2, 1, 0
  byte startindex = 0;
  switch (segment) {
    case 0:
      startindex = 0;
      break;
    case 1:
      startindex = 21;
      break;
    case 2:
      startindex = 44;
      break;
    case 3:
      startindex = 65;
      break;    
  }

  for (byte i=0; i<21; i++){
    yield();
    LEDs[i + startindex] = ((numbers[number] & 1 << i) == 1 << i) ? color : alternateColor;
  } 
}

void allBlank() {
  for (int i=0; i<NUM_LEDS; i++) {
    LEDs[i] = CRGB::Black;
  }
  FastLED.show();
}

void updateClock() {  
  RtcDateTime now = Rtc.GetDateTime();
  // printDateTime(now);    

  int hour = now.Hour();
  int mins = now.Minute();
  int secs = now.Second();

  if (hourFormat == 12 && hour > 12) {
    hour = hour - 12;
  } else if (hourFormat == 12 && hour == 0) {     //fix for midnight - 1 am, where previously showed "0" for hour
    hour = 12;
  }
    
  
  byte h1 = hour / 10;
  byte h2 = hour % 10;
  byte m1 = mins / 10;
  byte m2 = mins % 10;  
  byte s1 = secs / 10;
  byte s2 = secs % 10;
  
  CRGB color = clockColor;     //CRGB(r_val, g_val, b_val);

  if (h1 > 0 || (hourFormat == 24 && hour == 0))  //display leading zero for midnight when 24-hour display
    displayNumber(h1,3,color);
  else 
    displayNumber(10,3,color);  // Blank
    
  displayNumber(h2,2,color);
  displayNumber(m1,1,color);
  displayNumber(m2,0,color); 

  displayDots(color);  
}
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

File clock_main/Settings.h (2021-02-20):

// ===============================================================================
// Update these values to match your build and board type if not using D1 Mini
#define NUM_LEDS 86                           // Total of 86 LED's if built as shown    
#define MILLI_AMPS 6000                       // Update to match max milliamp output of your power suppy (or about 500 milliamp lower than max to be safe)
#define DATA_PIN D6                           // Change this if you are using another type of ESP board than a WeMos D1 Mini
#define COUNTDOWN_OUTPUT D5                   // Output pin to drive buzzer or other device upon countdown expiration
#define WIFIMODE 2                            // 0 = Only Soft Access Point, 1 = Only connect to local WiFi network with UN/PW, 2 = Both
#define MQTTMODE 1                            // 0 = Disable MQTT, 1 = Enable (will only be enabled if WiFi mode = 1 or 2 - broker must be on same network)
#define MQTTSERVER "192.168.1.108"            // IP Address (or url) of MQTT Broker. Use '0.0.0.0' if not enabling MQTT
#define MQTTPORT 1883                         // Port of MQTT Broker.  This is usually 1883
// Optional pushbuttons (colors listed match ones used in build instructions)
// All pins need to be LOW when button open or code modifications will be required in main sketch
#define MODE_PIN D3                           // Push button (white): Change Mode
#define V1_PIN D4                             // Push button (red): Visitor+/Minutes Add button
#define V0_PIN 3                              // Push button (green): Visitor-/Seconds Add button (RX pin)
#define H1_PIN D7                             // Push button (yellow): Home+/Countdown start button
#define H0_PIN 1                              // Push button (blue): Home-/Countdown stop/pause button (TX pin)

// ---------------------------------------------------------------------------------------------------------------
// Options - Defaults upon boot-up.  Most values can be updated via web app or via Home Assistant/MQTT  after boot
// ---------------------------------------------------------------------------------------------------------------

byte clockMode = 0;                             // Default mode at boot: 0=Clock, 1=Countdown, 2=Temperature, 3=Scoreboard
byte brightness = 255;                          // Default starting brightness at boot. 255=max brightness based on milliamp rating of power supply
byte temperatureSymbol = 13;                    // Default temp display: 12=Celcius, 13=Fahrenheit
float temperatureCorrection = -3.0;             // Temp from RTC module.  Generally runs "hot" due to heat from chip.  Adjust as needed.
unsigned long temperatureUpdatePeriod = 180000; // How often, in milliseconds to update MQTT time. Recommend minimum of 60000 (one minute) or greater. Set to 0 to disable updates.
byte hourFormat = 12;                           // Change this to 24 if you want default 24 hours format instead of 12     
byte scoreboardLeft = 0;                        // Starting "Visitor" (left) score on scoreboard
byte scoreboardRight = 0;                       // Starting "Home" (right) score on scoreboard

// Default starting colors for modes
// Named colors can be used.  Valid values found at: http://fastled.io/docs/3.1/struct_c_r_g_b.html
// Alternatively, you can specify each of the following as rgb values.  Example: CRGB clockColor = CRBG(0,0,255);

CRGB clockColor = CRGB:: Blue;
CRGB countdownColor = CRGB::Green;
CRGB countdownColorPaused = CRGB::Orange;     // If different from countdownColor, countdown color will change to this when paused/stopped.
CRGB countdownColorFinalMin = CRGB::Red;      // If different from countdownColor, countdown color will change to this for final 60 seconds.
CRGB temperatureColor = CRGB::Turquoise;
CRGB scoreboardColorLeft = CRGB::Red;
CRGB scoreboardColorRight = CRGB::Green;
CRGB alternateColor = CRGB::Black;            // Recommend to leave as Black. Otherwise unused pixels will be lit in digits

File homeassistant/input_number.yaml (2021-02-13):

# =========================================
#  LED Clock Brightness and Color Sliders
# =========================================
# LED Clock Brightness:
led_clock_brightness:
  name: LED Clock Brightness
  min: 0
  max: 255
  step: 1
  mode: slider
# LED Clock Clock Colors (R, G, B)
led_clock_color_red:
  name: Clock Color Red
  min: 0
  max: 255
  step: 1
  mode: slider
led_clock_color_green:
  name: Clock Color Green
  min: 0
  max: 255
  step: 1
  mode: slider
led_clock_color_blue:
  name: Clock Color Blue
  min: 0
  max: 255
  step: 1
  mode: slider
# LED Clock Countdown Color
led_clock_countdown_color_red:
  name: Countdown Active Color Red
  min: 0
  max: 255
  step: 1
  mode: slider
led_clock_countdown_color_green:
  name: Countdown Active Color Green
  min: 0
  max: 255
  step: 1
  mode: slider
led_clock_countdown_color_blue:
  name: Countdown Active Color Blue
  min: 0
  max: 255
  step: 1
  mode: slider
led_clock_countdown_color_paused_red:
  name: Countdown Paused Color Red
  min: 0
  max: 255
  step: 1
  mode: slider
led_clock_countdown_color_paused_green:
  name: Countdown Paused Color Green
  min: 0
  max: 255
  step: 1
  mode: slider
led_clock_countdown_color_paused_blue:
  name: Countdown Paused Color Blue
  min: 0
  max: 255
  step: 1
  mode: slider
led_clock_countdown_color_lastmin_red:
  name: Countdown Last Minute Color Red
  min: 0
  max: 255
  step: 1
  mode: slider
led_clock_countdown_color_lastmin_green:
  name: Countdown Last Minute Color Green
  min: 0
  max: 255
  step: 1
  mode: slider
led_clock_countdown_color_lastmin_blue:
  name: Countdown Last Minute Color Blue
  min: 0
  max: 255
  step: 1
  mode: slider
# LED Clock Temperature Color
led_clock_temperature_color_red:
  name: Temperature Color Red
  min: 0
  max: 255
  step: 1
  mode: slider
led_clock_temperature_color_green:
  name: Temperature Color Green
  min: 0
  max: 255
  step: 1
  mode: slider
led_clock_temperature_color_blue:
  name: Temperature Color Blue
  min: 0
  max: 255
  step: 1
  mode: slider
# LED Clock Scoreboard Colors
led_clock_scoreboard_color_left_red:
  name: Scoreboard Left Color Red
  min: 0
  max: 255
  step: 1
  mode: slider
led_clock_scoreboard_color_left_green:
  name: Scoreboard Left Color Green
  min: 0
  max: 255
  step: 1
  mode: slider
led_clock_scoreboard_color_left_blue:
  name: Scoreboard Left Color Blue
  min: 0
  max: 255
  step: 1
  mode: slider
led_clock_scoreboard_color_right_red:
  name: Scoreboard Right Color Red
  min: 0
  max: 255
  step: 1
  mode: slider
led_clock_scoreboard_color_right_green:
  name: Scoreboard Right Color Green
  min: 0
  max: 255
  step: 1
  mode: slider
led_clock_scoreboard_color_right_blue:
  name: Scoreboard Right Color Blue
  min: 0
  max: 255
  step: 1
  mode: slider

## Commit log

2021-02-13 Initial upload
    [AttachBrackets_x6.stl, Backlid.stl, Bottom.stl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]
2021-02-15 Update clock_main.ino
    Fixes for missing temperature MQTT updates in Home Assistant.
    [clock_main.ino]
2024-01-10 Fix for Issue #3
    [clock_main.ino]
